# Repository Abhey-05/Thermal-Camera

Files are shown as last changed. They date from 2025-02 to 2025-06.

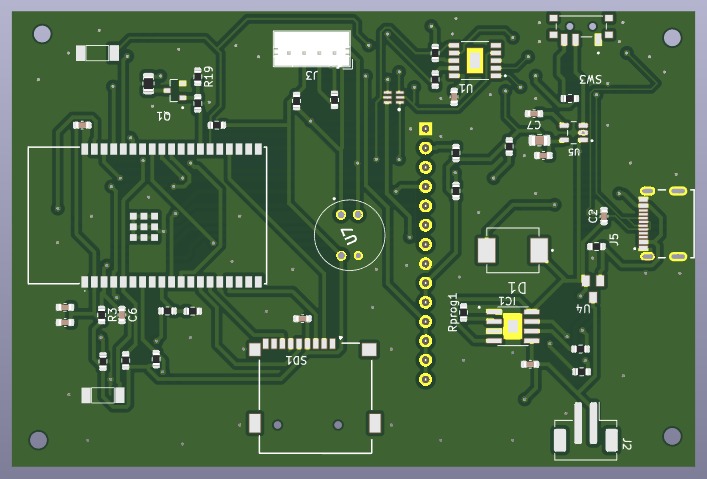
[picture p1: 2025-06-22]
Images/pcb2.jpeg

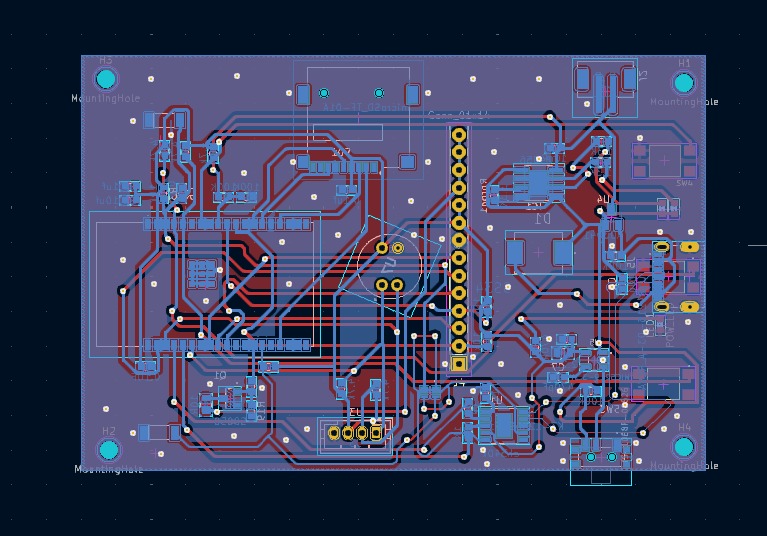
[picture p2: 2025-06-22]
Images/pcb3.jpeg

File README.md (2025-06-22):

<h1>
  Thermal Camera
</h1>
A compact, low-cost thermal imaging solution built for diagnostic, repair, and monitoring applications in electronics, industrial safety, and embedded systems. Unlike commercial thermal cameras that are often expensive, this DIY thermal imager is designed using readily available and affordable components, making it accessible for students, hobbyists, and engineers.

Thermal cameras play a critical role in detecting temperature anomalies, benchmarking heat performance, and assisting in electronic hardware debugging. Commonly used in defense, predictive maintenance, and the repair industry, thermal imaging enables faster and safer identification of faults such as short circuits or overheating components. Our project aims to replicate these capabilities at a fraction of the market cost.

<h2>Project Workflow </h2>

We began by understanding the working principles of thermal cameras and the core requirements of a low-cost system. The MLX90640 thermal sensor was selected for its high sensitivity and compact resolution, while the 2.4” TFT display offered a visually rich and user-friendly interface.

We wrote firmware from scratch to handle thermal data acquisition, color mapping, and display control using an ESP32 microcontroller. All SPI and I2C communication protocols were manually configured and tested for stability. We then implemented SD card image storage and added support for selectable color palettes and refresh rates.

The enclosure and power management were developed in parallel. A custom battery management system was integrated to allow portability, and the housing was designed to be compact yet thermally stable. The complete schematic and PCB were designed in KiCad.

<h2>
Features:
</h2>

- Image Sensor Resolution: 32×24 pixels
- Field of View (FoV): 55° × 35°
- Temperature Measurement Range: -40°C to 300°C
- Operating Temperature Range: -40°C to 85°C
- Adjustable Refresh Rate: 4 Hz to 32 Hz
- Color Palettes: 10 selectable thermal color schemes
- Display: 2.4" TFT screen with 320×240 resolution
- Storage: Supports saving thermal images to SD card
- Power: Built-in rechargeable battery with charging circuit

<h2>Schematic</h2>

WhatsApp Image 2025-06-22 at 16 25 18

<h2>PCB Layout </h2>

pcb1
pcb2
pcb3

<h2>Setup</h2>

WhatsApp Image 2025-06-22 at 16 26 38

<h2> Working Video </h2>

https://github.com/user-attachments/assets/c0b89b00-765c-46c9-96d5-a79226db0dfd

https://github.com/user-attachments/assets/fa7a4603-ffcd-4ff7-a3ee-2d5423cac2e8

<h2>Applications</h2>

- Electronics repair and thermal diagnostics
- Industrial safety monitoring
- DIY electronics and embedded systems projects
- Educational use for temperature visualization

<h2>Challenges Faced</h2>
 
- Occasional screen lag during rapid refresh.
- Difficulty in storing data reliably on the SD card due to SPI timing issues.
- Display showed only half-screen output initially, resolved through pin remapping and timing adjustments.

<h2>Team Members</h2>

- Abhey Garg (EE23BTECH11202)
- Chirag Garg (EE23BTECH11206)
- Prashant Maurya (EE23BTECH11218)
- Preetam (EE23BTECH11221)
- Sasa Mardi (EE23BTECH11222)

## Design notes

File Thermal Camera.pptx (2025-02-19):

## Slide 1

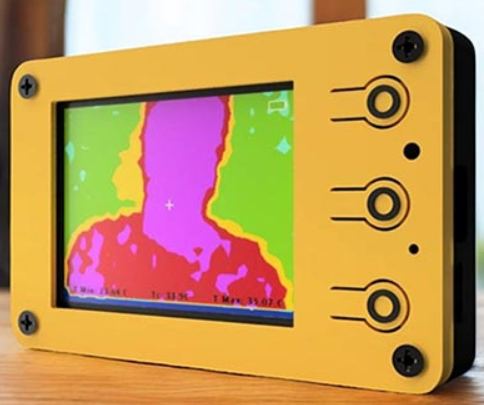
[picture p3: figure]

Thermal Sensing Camera

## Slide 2

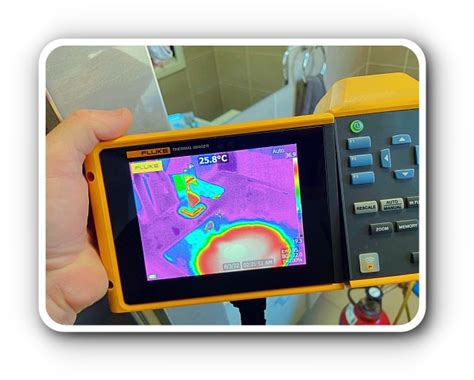
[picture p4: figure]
Thermal imaging | Water Leak Detection Pioneers

Project By:
Sasa Mardi ee23btech11222
Sai Preetam ee23btech11221
Abhey Garg ee23btech11202
Chirag Garg ee23btech11206
Prashant Maurya ee23btech11218

## Introduction

A DIY thermal camera using an ESP32 microcontroller and an MLX90640 thermal sensor offers an affordable and portable solution for thermal imaging. This project enables real-time heat detection by capturing infrared radiation and converting it into a visual temperature map displayed on an OLED or TFT screen. The ESP32 processes data from the MLX90640 sensor via the I2C protocol, rendering a thermal image that highlights temperature variations in the environment. Powered by a lithium-ion battery, this compact thermal camera is ideal for applications such as detecting heat loss in buildings, monitoring electronic components for overheating, and temperature screening.

## Major Components

1. IR SENSOR MLX90640 (32 x 24)
2. ESP32 Microcontroller
3. TFT Display(320 x 240)
4. Battery
5. SD Card

## Features

Sensor field of view (FoV): 55°x35°
Temperature measurement range: -40 to 300°C
-40 to 85°C operational temperature range
Adjustable refresh rate – 4Hz – 32Hz.10 different colour pallets
5 different interpolation modes.
Easy to use GUI.
2.4” TFT display with 320x240 resolution
Built-in battery and charging circuit.

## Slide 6

Power Input

3.3V Regulator

On/Off switch

Battery Charging

Display

LED Indicator

USB-UART/ Programming Circuit

ESP 32 SoC

Image Sensor

SD Card

## Work Flow

1. Data Acquisition: The MLX90640 sensor continuously reads the infrared radiation from its environment and transmits the data to the ESP32.
2. Data Processing: The ESP32 reads the data from the thermal sensor, processes the temperature information, and formats it into a readable thermal image.
3. Image Display: The processed data is sent to the display, where it is rendered as a color-coded thermal image. Different temperatures are represented by varying colors or shades.
4. Power Management: The battery supplies power to the ESP32 and the sensor, making it a portable system that can be used in a variety of environments.

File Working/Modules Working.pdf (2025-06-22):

# Thermal Camera System Design Overview

### USB Input and Power Path Control

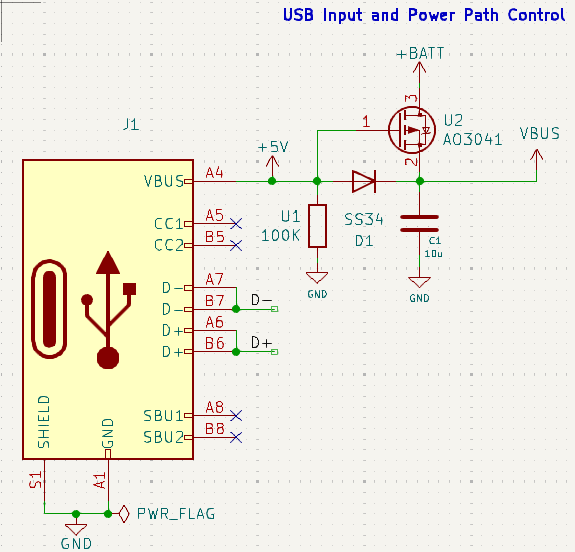
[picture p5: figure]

The USB input and power path control system is critical for managing the multiple power sources available to the thermal camera. It ensures the camera can operate seamlessly whether powered via USB or a battery.

A power multiplexer or ideal diode controller typically governs the transition, preventing back-powering and allowing simultaneous battery charging and device operation. The system must include overvoltage, overcurrent, and thermal protection mechanisms to ensure safety and reliability. Proper path control contributes to system robustness, ensuring no disruption when power sources are switched. This is essential for user convenience, especially in portable field use where the device may frequently switch between power modes.

### 3.3V Regulator

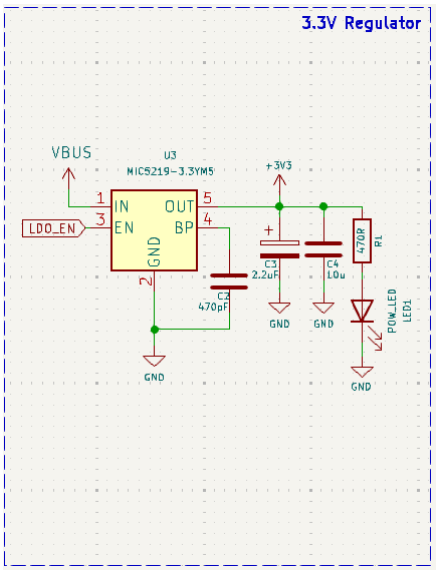
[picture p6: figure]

The 3.3V voltage regulator is tasked with converting a higher voltage (usually 5V from USB or battery boost converter) to a stable 3.3V rail. This is the operating voltage for key components like the ESP32 SoC, MLX90640 sensor, and display modules. Choosing between a linear regulator and a buck converter depends on system efficiency requirements. While linear regulators are simple, they waste excess voltage as heat.

Buck converters are more efficient, especially for battery applications, and reduce power loss. Clean 3.3V power is vital for stable wireless communication and accurate sensor data. Noise filtering and proper PCB layout techniques (e.g., decoupling capacitors) further enhance the stability of this power rail.

### Battery Charging Circuit

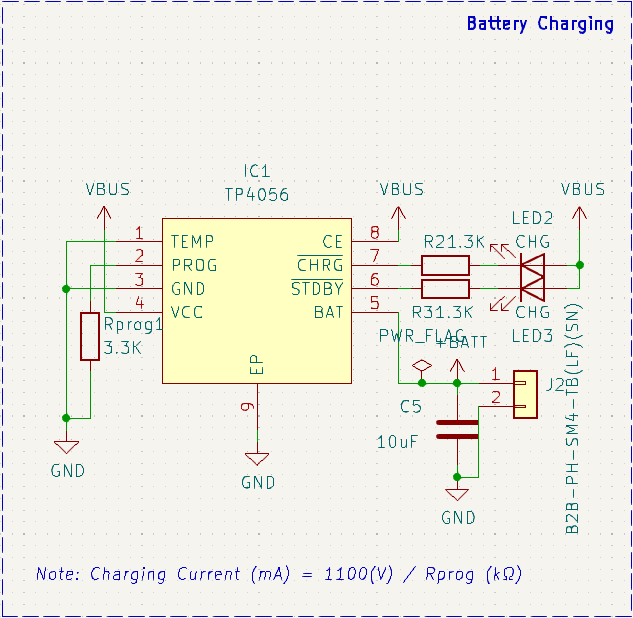
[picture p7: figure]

This module allows safe charging of a lithium-based battery pack from the USB input. It includes current regulation, voltage monitoring, and protection features such as thermal shutdown and trickle pre-charging for depleted cells.

A commonly used IC is the TP4056 or MCP73831. This circuit must be carefully designed to balance charge speed and battery lifespan.

It plays a crucial role in ensuring the thermal camera can be recharged quickly and safely while still operating. Additionally, some chargers support power path management, allowing the device to run off USB while the battery charges - an essential feature in mobile designs.

### TFT Display

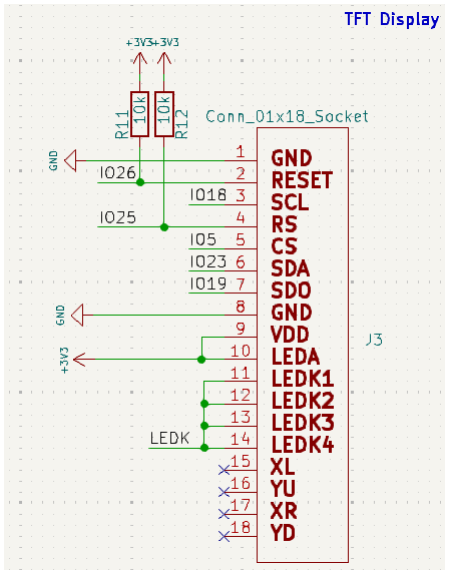
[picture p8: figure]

The TFT display acts as the primary output interface for the thermal camera, providing a graphical visualization of the thermal data. With resolutions like 240x320, it enables users to observe heat signatures and temperature gradients effectively.

It communicates with the ESP32 typically over SPI and requires careful initialization via display drivers. The display not only shows the thermal image but can also be used to display temperature values, color-coded heatmaps, or user menus.

Its size, resolution, and refresh rate significantly affect the user experience and system responsiveness. Good readability in various lighting conditions and low power consumption are key factors in selecting the right display.

### USB-UART Programming Circuit

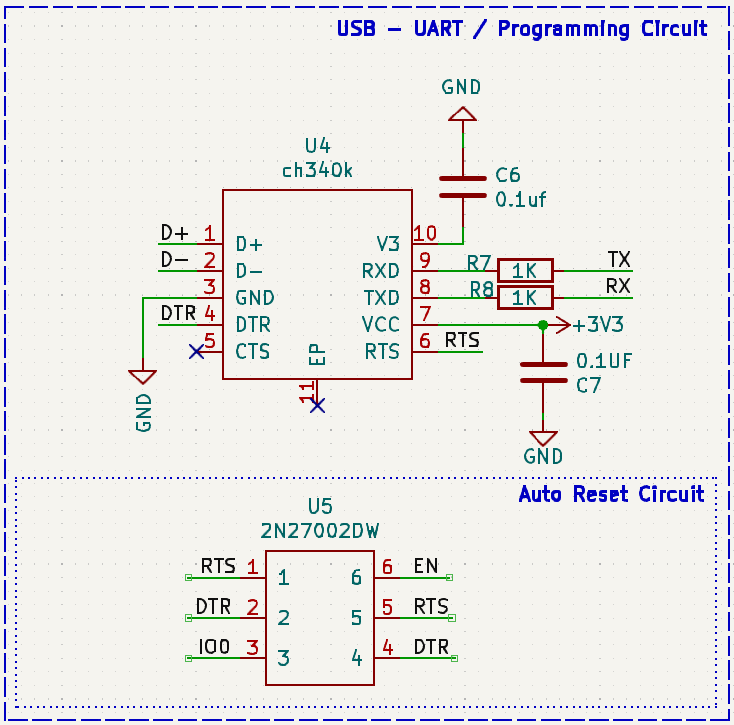
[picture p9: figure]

This circuit enables easy programming and debugging of the ESP32 via a USB connection. It includes a USB-to-serial converter chip such as CP2102, FTDI FT232, or CH340. This converter interfaces between the PC and the ESP32’s UART pins, allowing firmware uploads and serial communication.

It usually includes a DTR/RTS-driven auto-reset circuit for seamless programming from tools like the Arduino IDE or ESP-IDF. This circuit is vital during development and even useful in production for diagnostics. A reliable USB-UART bridge ensures consistent communication, enabling users to update firmware or log sensor data without opening the device.

### ESP32 SoC

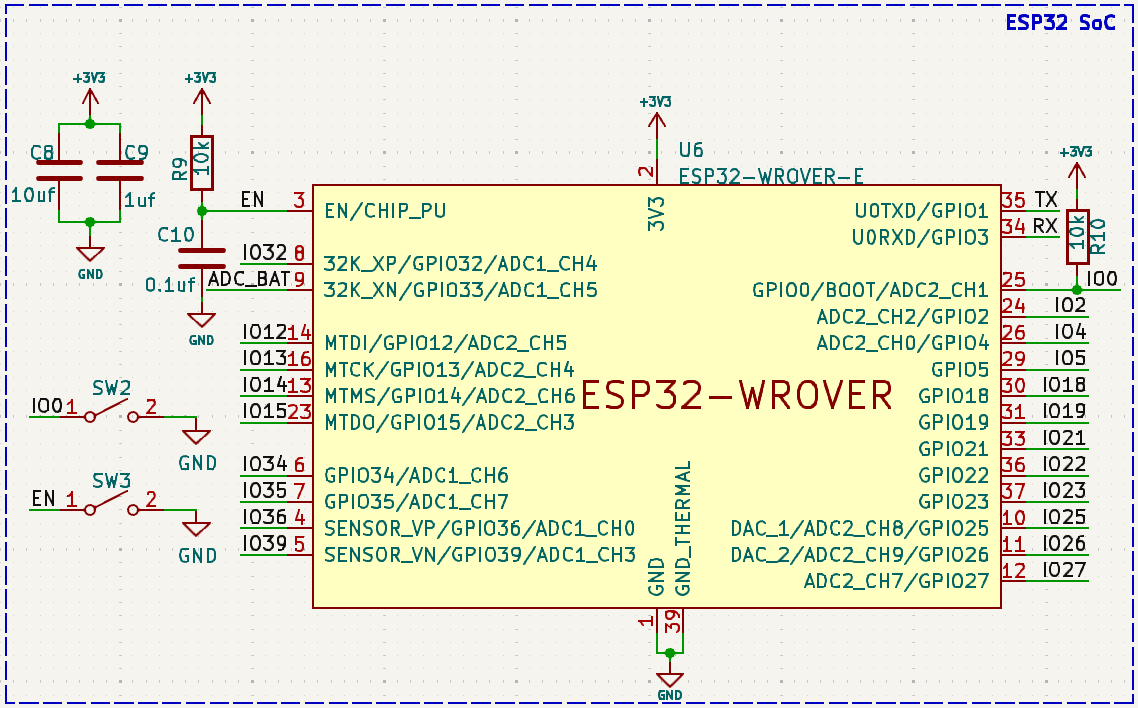
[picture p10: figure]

The ESP32 System-on-Chip (SoC) is the core of the thermal camera. It includes a dual-core processor, integrated Wi-Fi and Bluetooth, multiple GPIOs, ADCs, SPI/I2C/UART, and low-power modes. It interfaces with all peripherals, including the MLX90640 thermal sensor, the TFT display, and power management circuits. The ESP32 processes thermal data, applies temperature mapping algorithms, and renders visual outputs. Its wireless capabilities allow remote monitoring or control.

The ESP32’s programmability makes it ideal for embedded applications where performance, connectivity, and low power are needed. With adequate memory and speed, it handles image data and system control efficiently in real-time.

### MLX90640 Sensor

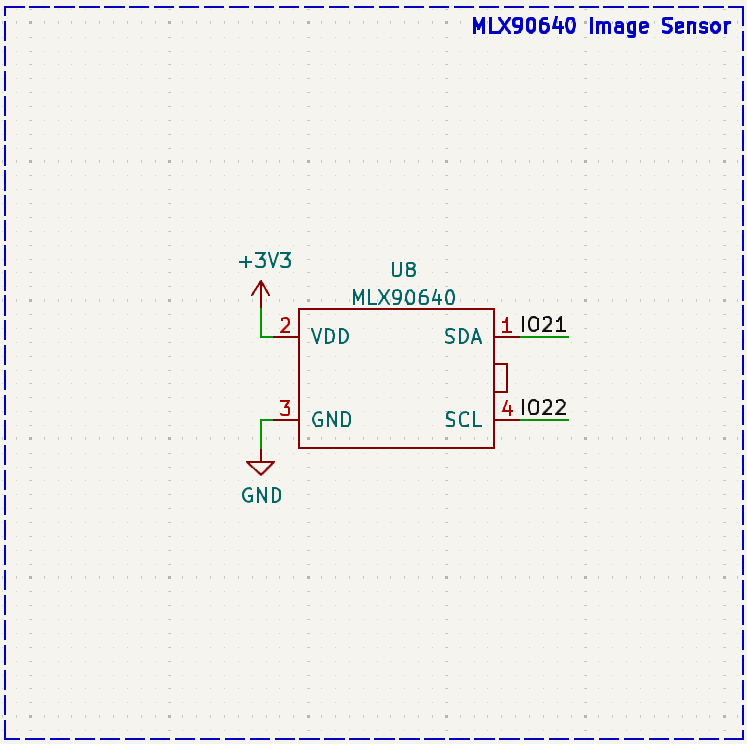
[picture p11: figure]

The MLX90640 is a 32x24 pixel thermal infrared sensor array that captures temperature data across its field of view. It senses infrared radiation to form a low-resolution thermal image and communicates with the ESP32 via I2C. Each pixel provides temperature readings that the ESP32 converts into a visual heat map. The sensor operates between -40°C to 300°C and is ideal for contactless temperature measurement. It includes onboard calibration and frame refresh control. Its compact size and low power consumption make it suitable for handheld thermal cameras.

Applications include human presence detection, energy audits, and heat leakage detection. It is the main imaging component of the thermal camera, delivering the raw thermal data essential for operation.

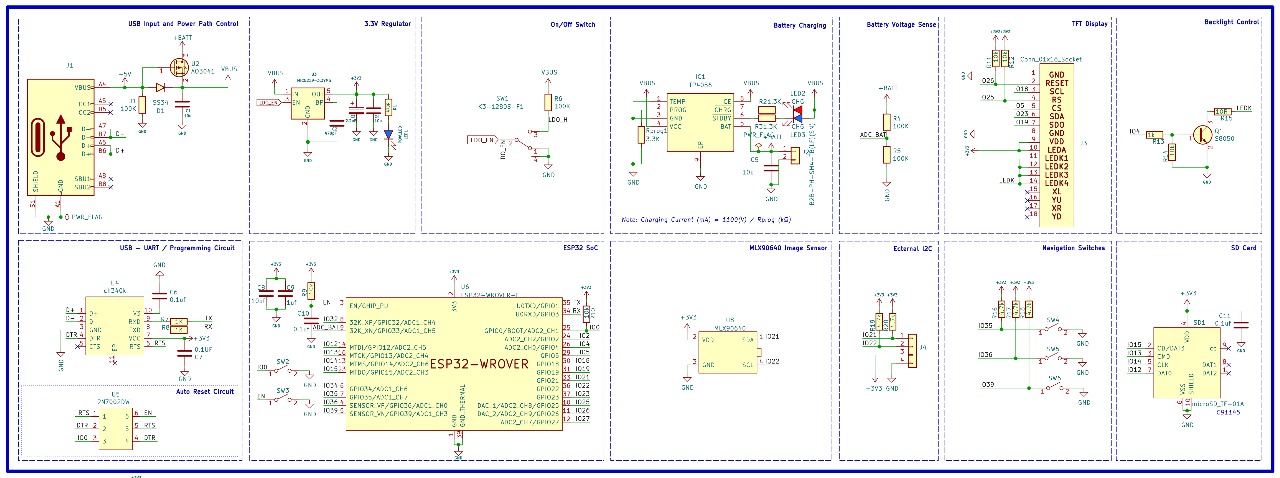
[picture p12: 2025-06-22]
Images/Schematic.jpeg

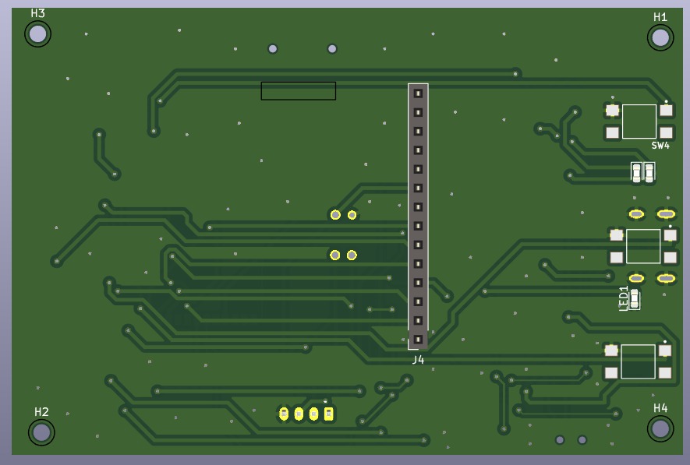
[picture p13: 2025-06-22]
Images/pcb1.jpeg

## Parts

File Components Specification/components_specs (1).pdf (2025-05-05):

# Component Specifications

# Contents

Component Specifications

## 0.1 ESP32-WROVER-E

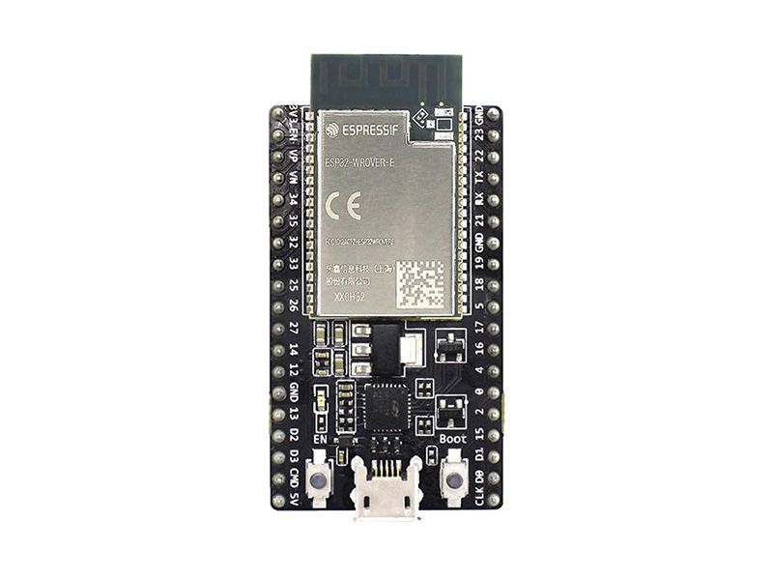
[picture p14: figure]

Figure 1: ESP32-WROVER-E Module

Specifications

- Chipset: ESP32-D0WD-V3 with dual-core Xtensa® 32-bit LX6 up to 240 MHz.
- Flash Memory: 4 MB external SPI flash.
- PSRAM: 8 MB SPI PSRAM.
- Wireless: Wi-Fi (802.11 b/g/n) + Bluetooth v4.2.
- Antenna: On-board or IPEX connector.
- Voltage: 3.0 V to 3.6 V (typical 3.3 V).
- Sleep Current: As low as 10 µA.
- GPIOs: 34.
- Interfaces: UART, SPI, I2C, etc.
- Peripherals: Hall sensor, temperature sensor, capacitive touch.
- Temperature: –40 °C to 85 °C.
- Dimensions: 18 × 31.4 × 3.3 mm.

## 0.2 MLX90640 Thermal Infrared Sensor

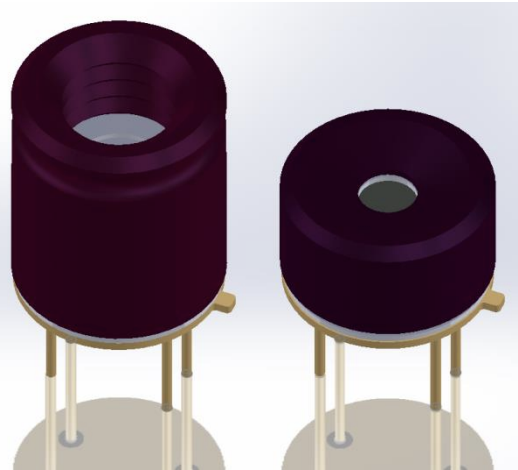
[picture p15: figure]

Figure 2: MLX90640 Thermal Sensor

Specifications

- Array: 32 × 24 pixels.
- Package: TO-39.
- Spectral Range: 7.5 – 13.5 µm.
- FOV: 55°×35°, 110°×75°, 40°×10°.
- Accuracy: ±1°C (0–50°C).
- Range: –40°C to +300°C.
- Sensitivity: 0.1 K.
- Voltage: 3.3V ±5%.
- Current: 23 mA.
- Interface: I²C.
- Frame Rate: 0.5 to 64 Hz.
- EEPROM: Internal.
- Pixel Pitch: 0.9 mm.
- Optical Axis: 6.52 mm from base.
- Size: 8.9 mm diameter × 10.9 mm height.
- Temp. Range: –40°C to +85°C (operating), –40°C to +125°C (storage).

## 0.3 LDO Voltage Regulator (XC6206P332MR)

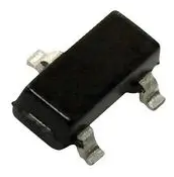
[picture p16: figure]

Figure 3: LDO Voltage Regulator

Specifications

- Model: XC6206P332MR
- Output Voltage: 3.3V
- Max Current: 250 mA
- Dropout: 250 mV @ 100 mA
- Input Range: 2.0V to 6.0V
- Accuracy: ±2%
- Quiescent Current: 8 µA
- Protection: Current limiter, thermal shutdown
- Package: SOT-23
- Applications: Battery systems, low-power microcontrollers

## 0.4 ILI9341 TFT Display

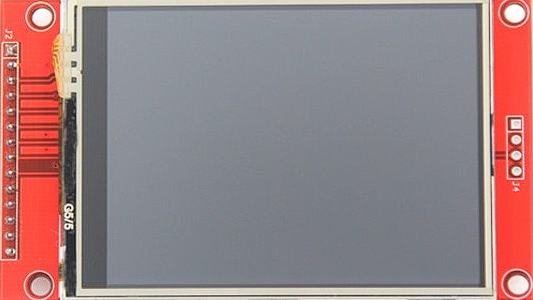
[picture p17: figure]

Figure 4: ILI9341 TFT Display

Specifications

- Type: TFT LCD
- Resolution: 240 × 320 pixels
- Size: 2.4” or 2.8”
- Colors: 262K
- Driver: ILI9341
- Interfaces: Parallel, SPI, RGB
- Voltages: 1.65V–3.3V (digital), 2.5V–3.3V (analog)
- Frame Memory: 172800 bytes
- Features: Power saving, display inversion, idle mode
- Touch: Not included
- Backlight: LED (external control)

## 0.5 CH340 USB to Serial Converter IC

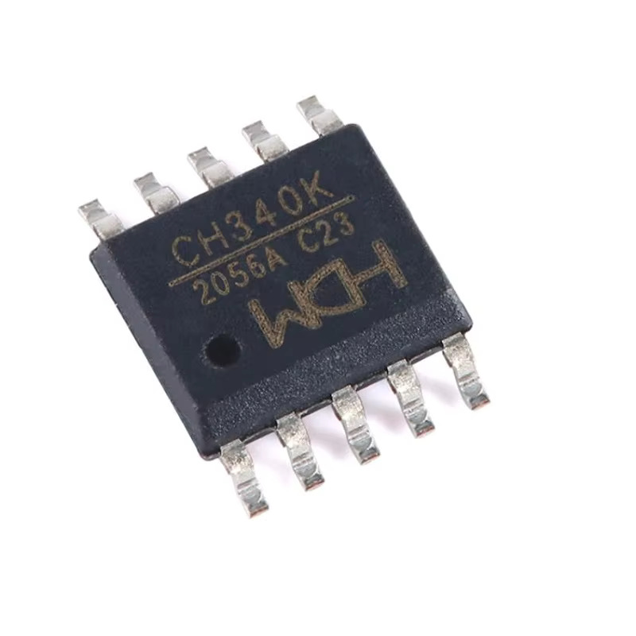
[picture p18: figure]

Figure 5: CH340 USB to Serial Converter IC

Specifications

- Type: USB to UART bridge
- USB: 1.1, 2.0, 3.0 compatible
- Voltage: 5V (CH340G), supports 3.3V logic
- Baud Rate: 50 bps to 2 Mbps
- Package: SOP-16
- Oscillator: 12 MHz crystal required
- Drivers: Needed on Windows
- Interfaces: TXD, RXD, RTS, CTS, etc.
- Flow Control: Hardware software supported
- Applications: USB-to-serial, embedded systems

## 0.6 TP4056 Li-Ion Battery Charging IC

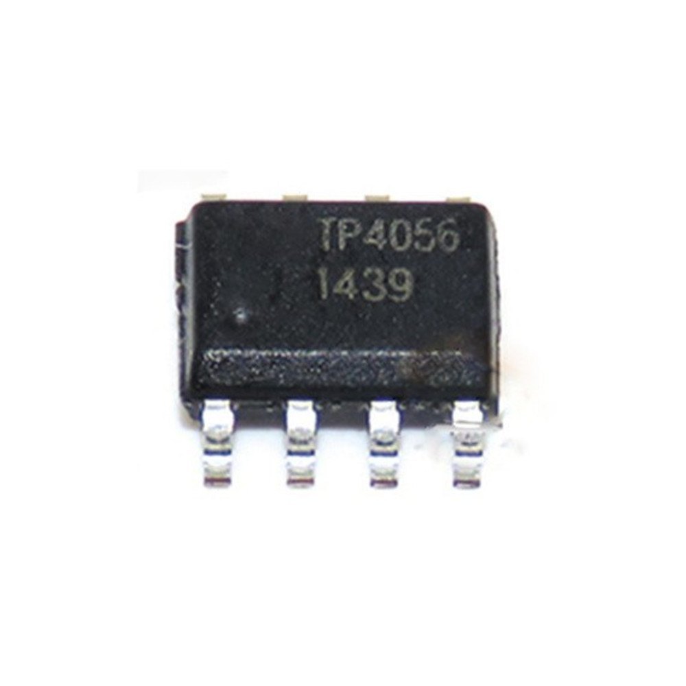
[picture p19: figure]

Figure 6: TP4056 Charging IC

Specifications

- Type: Linear Li-Ion Charger
- Charge Voltage: 4.2V
- Charge Current: Up to 1000 mA
- Package: ESOP-8
- Input Voltage: 4.0V to 8.0V
- Indication: STAT pin (active low)
- Trickle Threshold: 2.9V
- Accuracy: ±1.5%
- Standby Current: 100 µA
- Protections: Thermal, battery temp, recharge
- Applications: Power banks, portable devices

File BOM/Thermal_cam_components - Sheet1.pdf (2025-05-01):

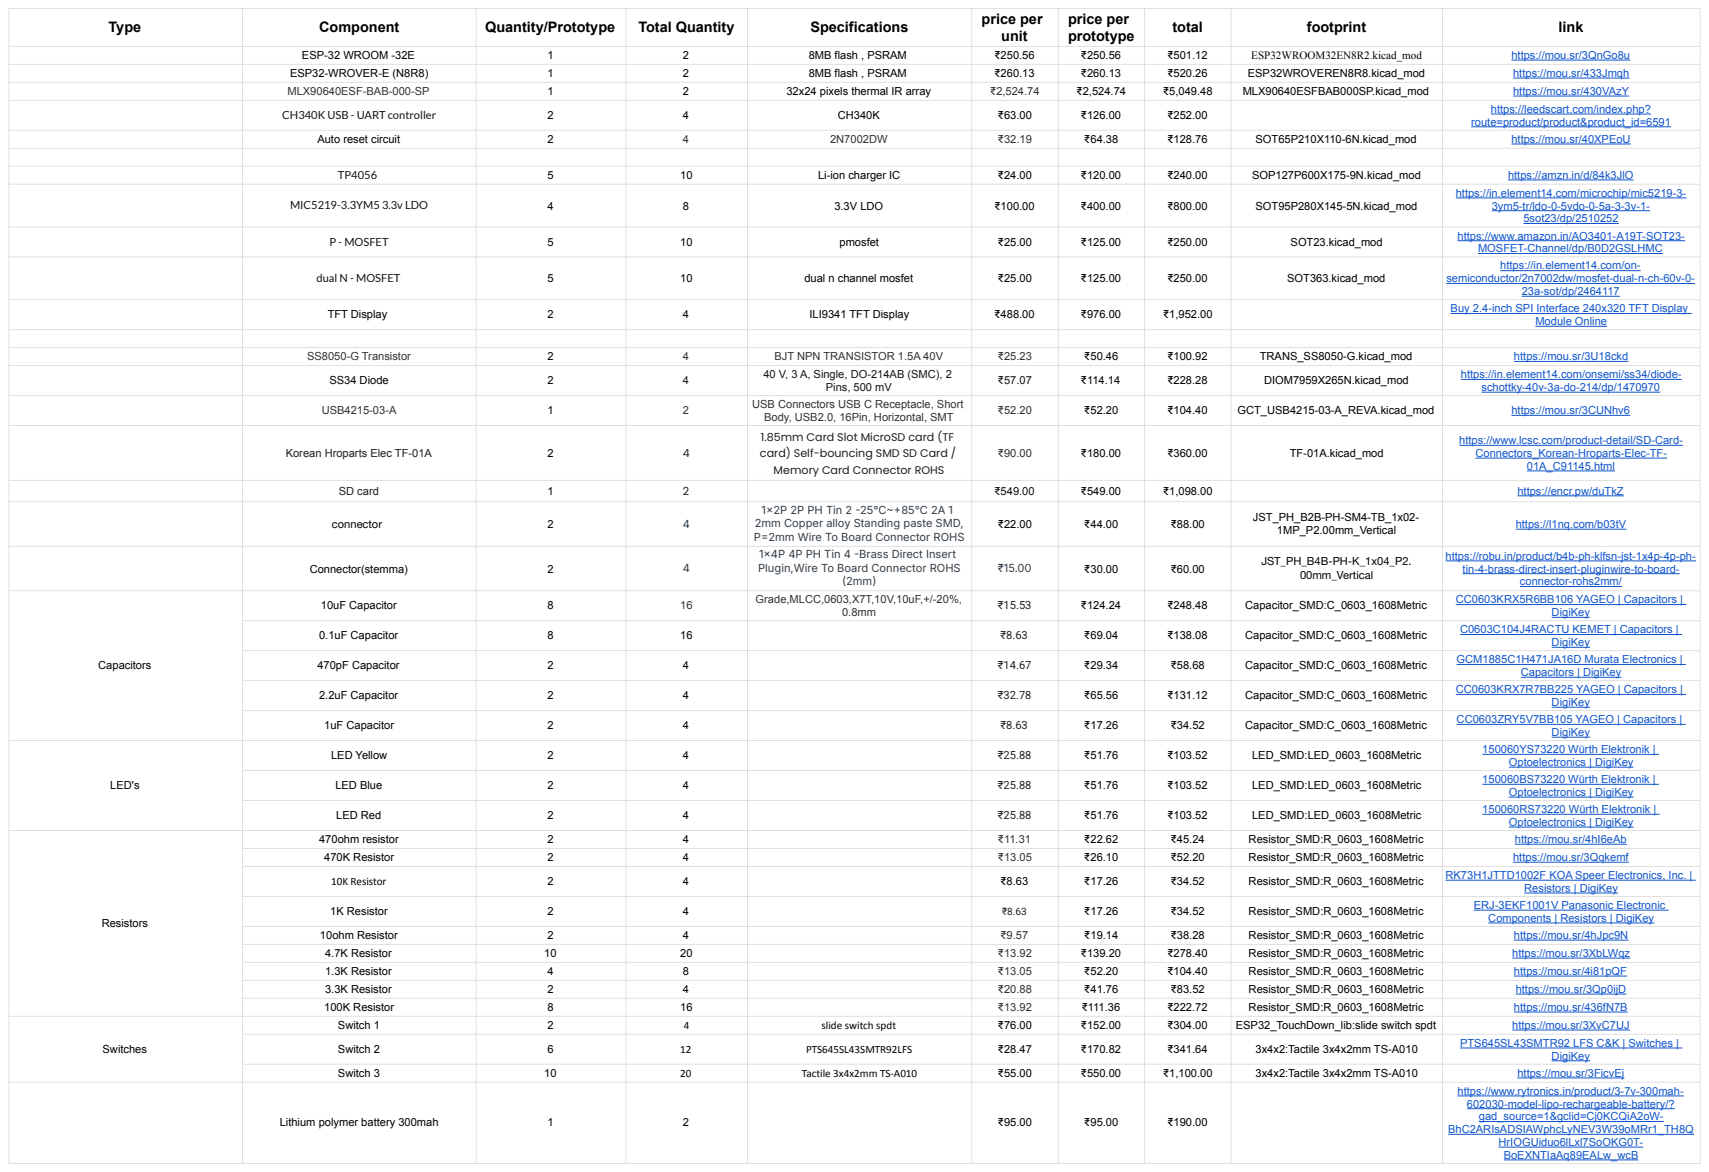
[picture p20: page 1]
Type; Component; Quantity/Prototype; Total Quantity; Specifications; price per unit; price per; prototype; total; footprint; link; ESP-32 WROOM -32E; 8MB flash , PSRAM; ESP32WROOM32EN8R2.kicad_mod; https://mou.sr/3QnGo8u; ESP32-WROVER-E (N8R8); ESP32WROVEREN8R8.kicad_mod; https://mou.sr/433Jmqh MLX90640ESF-BAB-000-SP; 32x24 pixels thermal IR array; MLX90640ESFBAB000SP.kicad_mod; https://mou.sr/430VAzY; Li-ion charger IC; SOP127P600X175-9N.kicad_mod; https://amzn.in/d/84k3JlO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

CH340K USB - UART controller | 2 4 CH340K ₹63.00 ₹126.00 ₹252.00 https://leedscart.com/index.php?route=product/product&product_id=6591 (https://www.lcsc.com/product-detail/USB-Converters_WCH-Jiangsu-Qin-Heng-CH340K_C968586.html)

Auto reset circuit 2 | 4 2N7002DW ₹32.19 | ₹64.38 ₹128.76 SOT65P210X110-6N.kicad_mod https://mou.sr/40XPEoU

https://in.element14.com/microchip/mic5219-3- 3ym5-tr/ldo-0-5vdo-0-5a-3-3v-1- 5sot23/dp/2510252

semiconductor/2n7002dw/mosfet-dual-n-ch-60v-0- (https://in.element14.com/on-semiconductor/2n7002dw/mosfet-dual-n-ch-60v-0-23a-sot/dp/2464117) 23a-sot/dp/2464117

https://in.element14.com/on-

SS8050-G Transistor 2 SS34 Diode 2 USB4215-03-A 1 | 4 BJT NPN TRANSISTOR 1.5A 40V ₹25.23 40 V, 3 A, Single, DO-214AB (SMC), 2 Pins, 500 mV ₹57.07 4 2 USB Connectors USB C Receptacle, Short Body, USB2.0, 16Pin, Horizontal, SMT ₹52.20 | ₹50.46 ₹100.92 TRANS_SS8050-G.kicad_mod https://mou.sr/3U18ckd ₹114.14 ₹228.28 DIOM7959X265N.kicad_mod https://in.element14.com/onsemi/ss34/diode-schottky-40v-3a-do-214/dp/1470970 (https://in.element14.com/onsemi/ss34/diode-schottky-40v-3a-do-214/dp/1470970) ₹52.20 ₹104.40 GCT_USB4215-03-A_REVA.kicad_mod https://mou.sr/3CUNhv6

Korean Hroparts Elec TF-01A SD card | 2 1 | 1.85mm Card Slot MicroSD card (TF 4 card) Self-bouncing SMD SD Card / ₹90.00 Memory Card Connector ROHS 2 ₹549.00 | https://www.lcsc.com/product-detail/SD-Card- Connectors_Korean-Hroparts-Elec-TF- 01A_C91145.html ₹180.00 ₹360.00 TF-01A.kicad_mod ₹549.00 ₹1,098.00 https://encr.pw/duTkZ

12P 2P PH Tin 2 25℃85℃ 2A 1 2mm Copper alloy Standing paste SMD, P2mm Wire To Board Connector ROHS 14P 4P PH Tin 4 Brass Direct Insert Plugin,Wire To Board Connector ROHS 2mm | ₹22.00 ₹44.00 ₹88.00 JST_PH_B2B-PH-SM4-TB_1x02- 1MP_P2.00mm_Vertical https://l1nq.com/b03tV

₹15.00 | https://robu.in/product/b4b-ph-klfsn-jst-1x4p-4p-ph-₹30.00 ₹60.00 JST_PH_B4B-PH-K_1x04_P2. 00mm_Vertical

tin-4-brass-direct-insert-pluginwire-to-board-

https://www.rytronics.in/product/3-7v-300mah- 602030-model-lipo-rechargeable-battery/?

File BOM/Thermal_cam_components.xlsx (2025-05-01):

Type | Component | Quantity/Prototype | Total Quantity | Specifications | price per unit | price per prototype | total | footprint | link
 | ESP-32 WROOM -32E | 1 | 2 | 8MB flash , PSRAM | ₹250.56 | ₹250.56 | ₹501.12 | ESP32WROOM32EN8R2.kicad_mod | https://mou.sr/3QnGo8u
 | ESP32-WROVER-E (N8R8) | 1 | 2 | 8MB flash , PSRAM | ₹260.13 | ₹260.13 | ₹520.26 | ESP32WROVEREN8R8.kicad_mod | https://mou.sr/433Jmqh
 | MLX90640ESF-BAB-000-SP | 1 | 2 | 32x24 pixels thermal IR array | ₹2524.74 | ₹2524.74 | ₹5049.48 | MLX90640ESFBAB000SP.kicad_mod | https://mou.sr/430VAzY
 | CH340K USB - UART controller | 2 | 4 | CH340K | ₹63.00 | ₹126.00 | ₹252.00 |  | https://leedscart.com/index.php?route=product/product&product_id=6591 (https://www.lcsc.com/product-detail/USB-Converters_WCH-Jiangsu-Qin-Heng-CH340K_C968586.html)
 | Auto reset circuit | 2 | 4 | 2N7002DW | ₹32.19 | ₹64.38 | ₹128.76 | SOT65P210X110-6N.kicad_mod | https://mou.sr/40XPEoU
 | TP4056 | 5 | 10 | Li-ion charger IC | ₹24.00 | ₹120.00 | ₹240.00 | SOP127P600X175-9N.kicad_mod | https://amzn.in/d/84k3JlO
 | MIC5219-3.3YM5 3.3v LDO | 4 | 8 | 3.3V LDO | ₹100.00 | ₹400.00 | ₹800.00 | SOT95P280X145-5N.kicad_mod | https://in.element14.com/microchip/mic5219-3-3ym5-tr/ldo-0-5vdo-0-5a-3-3v-1-5sot23/dp/2510252
 | P - MOSFET | 5 | 10 | pmosfet | ₹25.00 | ₹125.00 | ₹250.00 | SOT23.kicad_mod | https://www.amazon.in/AO3401-A19T-SOT23-MOSFET-Channel/dp/B0D2GSLHMC
 | dual N - MOSFET | 5 | 10 | dual n channel mosfet | ₹25.00 | ₹125.00 | ₹250.00 | SOT363.kicad_mod | https://in.element14.com/on-semiconductor/2n7002dw/mosfet-dual-n-ch-60v-0-23a-sot/dp/2464117
 | TFT Display | 2 | 4 | ILI9341 TFT Display | ₹488.00 | ₹976.00 | ₹1952.00 |  | Buy 2.4-inch SPI Interface 240x320 TFT Display Module Online (https://robu.in/product/2-4-inch-spi-interface-240x320-touch-screen-tft-display-module/)
 | SS8050-G Transistor | 2 | 4 | BJT NPN TRANSISTOR 1.5A 40V | ₹25.23 | ₹50.46 | ₹100.92 | TRANS_SS8050-G.kicad_mod | https://mou.sr/3U18ckd
 | SS34 Diode | 2 | 4 | 40 V, 3 A, Single, DO-214AB (SMC), 2 Pins, 500 mV | ₹57.07 | ₹114.14 | ₹228.28 | DIOM7959X265N.kicad_mod | https://in.element14.com/onsemi/ss34/diode-schottky-40v-3a-do-214/dp/1470970
 | USB4215-03-A | 1 | 2 | USB Connectors USB C Receptacle, Short Body, USB2.0, 16Pin, Horizontal, SMT | ₹52.20 | ₹52.20 | ₹104.40 | GCT_USB4215-03-A_REVA.kicad_mod | https://mou.sr/3CUNhv6
 | Korean Hroparts Elec TF-01A | 2 | 4 | 1.85mm Card Slot MicroSD card (TF card) Self-bouncing SMD SD Card / Memory Card Connector ROHS | ₹90.00 | ₹180.00 | ₹360.00 | TF-01A.kicad_mod | https://www.lcsc.com/product-detail/SD-Card-Connectors_Korean-Hroparts-Elec-TF-01A_C91145.html
 | SD card | 1 | 2 |  | ₹549.00 | ₹549.00 | ₹1098.00 |  | https://encr.pw/duTkZ
 | connector | 2 | 4 | 1x2P 2P PH Tin 2 -25℃~+85℃ 2A 1 2mm Copper alloy Standing paste SMD,P=2mm Wire To Board Connector ROHS | ₹22.00 | ₹44.00 | ₹88.00 | JST_PH_B2B-PH-SM4-TB_1x02-1MP_P2.00mm_Vertical | https://l1nq.com/b03tV
 | Connector(stemma) | 2 | 4 | 1x4P 4P PH Tin 4 -Brass Direct Insert Plugin,Wire To Board Connector ROHS(2mm) | ₹15.00 | ₹30.00 | ₹60.00 | JST_PH_B4B-PH-K_1x04_P2.00mm_Vertical | https://robu.in/product/b4b-ph-klfsn-jst-1x4p-4p-ph-tin-4-brass-direct-insert-pluginwire-to-board-connector-rohs2mm/
Capacitors | 10uF Capacitor | 8 | 16 | Grade,MLCC,0603,X7T,10V,10uF,+/-20%,0.8mm | ₹15.53 | ₹124.24 | ₹248.48 | Capacitor_SMD:C_0603_1608Metric | CC0603KRX5R6BB106 YAGEO | Capacitors | DigiKey (https://www.digikey.in/en/products/detail/yageo/CC0603KRX5R6BB106/5195191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)
 | 0.1uF Capacitor | 8 | 16 |  | ₹8.63 | ₹69.04 | ₹138.08 | Capacitor_SMD:C_0603_1608Metric | C0603C104J4RACTU KEMET | Capacitors | DigiKey (https://www.digikey.in/en/products/detail/kemet/C0603C104J4RACTU/411096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)
 | 470pF Capacitor | 2 | 4 |  | ₹14.67 | ₹29.34 | ₹58.68 | Capacitor_SMD:C_0603_1608Metric | GCM1885C1H471JA16D Murata Electronics | Capacitors | DigiKey (https://www.digikey.in/en/products/detail/murata-electronics/GCM1885C1H471JA16D/1765213)
 | 2.2uF Capacitor | 2 | 4 |  | ₹32.78 | ₹65.56 | ₹131.12 | Capacitor_SMD:C_0603_1608Metric | CC0603KRX7R7BB225 YAGEO | Capacitors | DigiKey (https://www.digikey.in/en/products/detail/yageo/CC0603KRX7R7BB225/7164374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)
 | 1uF Capacitor | 2 | 4 |  | ₹8.63 | ₹17.26 | ₹34.52 | Capacitor_SMD:C_0603_1608Metric | CC0603ZRY5V7BB105 YAGEO | Capacitors | DigiKey (https://www.digikey.in/en/products/detail/yageo/CC0603ZRY5V7BB105/2103110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)
LED's | LED Yellow | 2 | 4 |  | ₹25.88 | ₹51.76 | ₹103.52 | LED_SMD:LED_0603_1608Metric | 150060YS73220 Würth Elektronik | Optoelectronics | DigiKey (https://www.digikey.in/en/products/detail/w%C3%BCrth-elektronik/150060YS73220/8557163)
 | LED Blue | 2 | 4 |  | ₹25.88 | ₹51.76 | ₹103.52 | LED_SMD:LED_0603_1608Metric | 150060BS73220 Würth Elektronik | Optoelectronics | DigiKey (https://www.digikey.in/en/products/detail/w%C3%BCrth-elektronik/150060BS73220/8557159)
 | LED Red | 2 | 4 |  | ₹25.88 | ₹51.76 | ₹103.52 | LED_SMD:LED_0603_1608Metric | 150060RS73220 Würth Elektronik | Optoelectronics | DigiKey (https://www.digikey.in/en/products/detail/w%C3%BCrth-elektronik/150060RS73220/8557161)
Resistors | 470ohm resistor | 2 | 4 |  | ₹11.31 | ₹22.62 | ₹45.24 | Resistor_SMD:R_0603_1608Metric | https://mou.sr/4hI6eAb
 | 470K Resistor | 2 | 4 |  | ₹13.05 | ₹26.10 | ₹52.20 | Resistor_SMD:R_0603_1608Metric | https://mou.sr/3Qqkemf
 | 10K Resistor | 2 | 4 |  | ₹8.63 | ₹17.26 | ₹34.52 | Resistor_SMD:R_0603_1608Metric | RK73H1JTTD1002F KOA Speer Electronics, Inc. | Resistors | DigiKey (https://www.digikey.in/en/products/detail/koa-speer-electronics-inc/RK73H1JTTD1002F/9844954)
 | 1K Resistor | 2 | 4 |  | ₹8.63 | ₹17.26 | ₹34.52 | Resistor_SMD:R_0603_1608Metric | ERJ-3EKF1001V Panasonic Electronic Components | Resistors | DigiKey (https://www.digikey.in/en/products/detail/panasonic-electronic-components/ERJ-3EKF1001V/196032)
 | 10ohm Resistor | 2 | 4 |  | ₹9.57 | ₹19.14 | ₹38.28 | Resistor_SMD:R_0603_1608Metric | https://mou.sr/4hJpc9N
 | 4.7K Resistor | 10 | 20 |  | ₹13.92 | ₹139.20 | ₹278.40 | Resistor_SMD:R_0603_1608Metric | https://mou.sr/3XbLWqz
 | 1.3K Resistor | 4 | 8 |  | ₹13.05 | ₹52.20 | ₹104.40 | Resistor_SMD:R_0603_1608Metric | https://mou.sr/4i81pQF
 | 3.3K Resistor | 2 | 4 |  | ₹20.88 | ₹41.76 | ₹83.52 | Resistor_SMD:R_0603_1608Metric | https://mou.sr/3Qp0ijD
 | 100K Resistor | 8 | 16 |  | ₹13.92 | ₹111.36 | ₹222.72 | Resistor_SMD:R_0603_1608Metric | https://mou.sr/436fN7B
Switches | Switch 1 | 2 | 4 | slide switch spdt | ₹76.00 | ₹152.00 | ₹304.00 | ESP32_TouchDown_lib:slide switch spdt | https://mou.sr/3XvC7UJ
 | Switch 2 | 6 | 12 | PTS645SL43SMTR92LFS | ₹28.47 | ₹170.82 | ₹341.64 | 3x4x2:Tactile 3x4x2mm TS-A010 | PTS645SL43SMTR92 LFS C&K | Switches | DigiKey (https://www.digikey.in/en/products/detail/c-k/PTS645SL43SMTR92-LFS/3861373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)
 | Switch 3 | 10 | 20 | Tactile 3x4x2mm TS-A010 | ₹55.00 | ₹550.00 | ₹1100.00 | 3x4x2:Tactile 3x4x2mm TS-A010 | https://mou.sr/3FicvEj
 | Lithium polymer battery 300mah | 1 | 2 |  | ₹95.00 | ₹95.00 | ₹190.00 |  | https://www.rytronics.in/product/3-7v-300mah-602030-model-lipo-rechargeable-battery/?gad_source=1

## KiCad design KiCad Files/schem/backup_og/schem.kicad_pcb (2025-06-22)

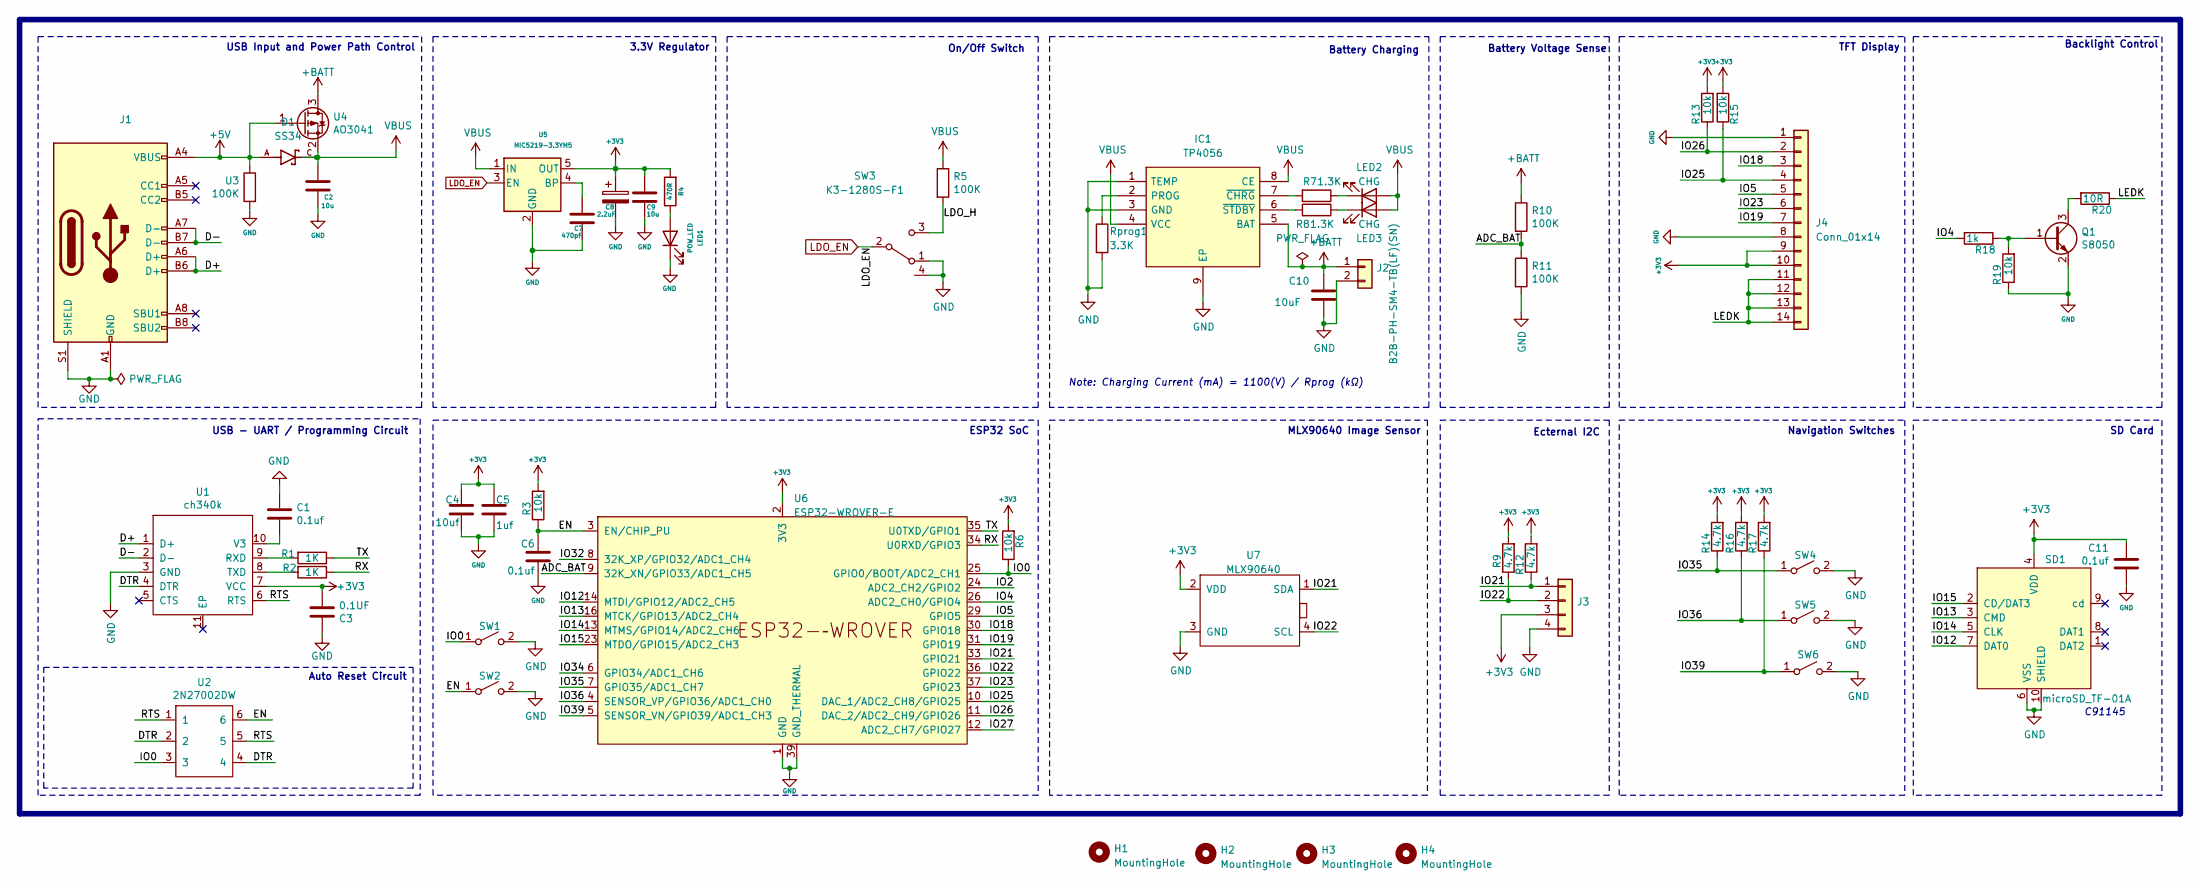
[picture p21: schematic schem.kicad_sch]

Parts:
C1, C6, C11: 0.1uf; C_0603_1608Metric
C2, C9: 10u; C_0603_1608Metric
C3: 0.1UF; C_0603_1608Metric
C4: 10uf; C_0603_1608Metric
C5: 1uf; C_0603_1608Metric
C7: 470pF; C_0603_1608Metric
C8: 2.2uF; C_0805_2012Metric
C10: 10uF; C_0603_1608Metric
D1: SS34; SS34_DIODE_NEW; PARTREV 31 Aug 2016
H1, H2, H3, H4: MountingHole; MountingHole_2.2mm_M2_ISO7380_Pad
IC1: TP4056; TP4056_SOP127P600X175-9N_TC; Manufacturer_Part_Number TP4056-42-ESOP8
J1: USB_C_Receptacle_USB2.0; USB_C_Receptacle_HRO_TYPE-C-31-M-12
J2: B2B-PH-SM4-TB(LF)(SN); JST_PH_B2B-PH-SM4-TB_1x02-1MP_P2.00mm_Vertical
J3: Stemma; JST_PH_B4B-PH-K_1x04_P2.00mm_Vertical
J4: Conn_01x14; PinSocket_1x14_P2.54mm_Vertical
LED1: POW_LED; LED_0603_1608Metric
LED2, LED3: CHG; LED_0603_1608Metric
Q1: S8050; TRANS_SS8050-G_TC
R1, R2: 1K; R_0603_1608Metric
R3, R6, R13, R15, R19: 10k; R_0603_1608Metric
R4: 470R; R_0603_1608Metric
R5, R10, R11: 100K; R_0603_1608Metric
R7, R8: 1.3K; R_0603_1608Metric
R9, R12, R14, R16, R17: 4.7k; R_0603_1608Metric
R18: 1k; R_0603_1608Metric
R20: 10R; R_0805_2012Metric
Rprog1: 3.3K; R_0603_1608Metric
SD1: microSD_TF-01A; sdcard_reader_TC
SW1, SW2: TS-1088R-02526; 2_TACTILE
SW3: K3-1280S-F1; slide_switch_TC
SW4, SW5, SW6: TS-1088R-02526; 4_TERMINAL_SWITCH_TC
U1: ch340k; ch340k_TC
U2: 2N27002DW; 2N7002DW_SOT363_TC
U3: 100K; R_0603_1608Metric
U4: AO3041; AO3401_SOT23_TC
U5: MIC5219-3.3YM5; MIC5219_SOT95P280X145-5N_TC
U6: ESP32-WROVER-E; ESP32WROVEREN8R8_TC
U7: MLX90640; MLX90640_ESFBAB000SP_TC

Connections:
+3V3: C3.2, C4.1, C5.1, C8.1, C9.1, C11.1, J3.3, J4.9, J4.10, R3.2, R4.2, R6.2, R9.2, R12.2, R13.2, R14.2, R15.2, R16.2, R17.2, SD1.4 (VDD), U1.7 (VCC), U5.5 (OUT), U6.2 (3V3), U7.2 (VDD)
+5V: D1.A, J1.A4 (VBUS), J1.A9 (VBUS), J1.B4 (VBUS), J1.B9 (VBUS), U3.1, U4.1 (G)
+BATT: C10.1, IC1.5 (BAT), J2.1, R10.1, U4.3 (D)
/ADC_BAT: R10.2, R11.1, U6.9 (32K_XN/GPIO33/ADC1_CH5)
/D+: J1.A6 (D+), J1.B6 (D+), U1.1 (D+)
/D-: J1.A7 (D-), J1.B7 (D-), U1.2 (D-)
/DTR: U1.4 (DTR), U2.2, U2.4
/EN: C6.1, R3.1, SW2.1 (A), U2.6, U6.3 (EN/CHIP_PU)
/IO0: R6.1, SW1.1 (A), U2.3, U6.25 (GPIO0/BOOT/ADC2_CH1)
/IO2: U6.24 (ADC2_CH2/GPIO2)
/IO4: R18.2, U6.26 (ADC2_CH0/GPIO4)
/IO5: J4.5, U6.29 (GPIO5)
/IO12: SD1.7 (DAT0), U6.14 (MTDI/GPIO12/ADC2_CH5)
/IO13: SD1.3 (CMD), U6.16 (MTCK/GPIO13/ADC2_CH4)
/IO14: SD1.5 (CLK), U6.13 (MTMS/GPIO14/ADC2_CH6)
/IO15: SD1.2 (CD/DAT3), U6.23 (MTDO/GPIO15/ADC2_CH3)
/IO18: J4.3, U6.30 (GPIO18)
/IO19: J4.7, U6.31 (GPIO19)
/IO21: J3.1, R12.1, U6.33 (GPIO21), U7.1 (SDA)
/IO22: J3.2, R9.1, U6.36 (GPIO22), U7.4 (SCL)
/IO23: J4.6, U6.37 (GPIO23)
/IO25: J4.4, R15.1, U6.10 (DAC_1/ADC2_CH8/GPIO25)
/IO26: J4.2, R13.1, U6.11 (DAC_2/ADC2_CH9/GPIO26)
/IO27: U6.12 (ADC2_CH7/GPIO27)
/IO32: U6.8 (32K_XP/GPIO32/ADC1_CH4)
/IO34: U6.6 (GPIO34/ADC1_CH6)
/IO35: R14.1, SW4.1 (A), U6.7 (GPIO35/ADC1_CH7)
/IO36: R16.1, SW5.1 (A), U6.4 (SENSOR_VP/GPIO36/ADC1_CH0)
/IO39: R17.1, SW6.1 (A), U6.5 (SENSOR_VN/GPIO39/ADC1_CH3)
/LDO_H: R5.2, SW3.3 (C)
/LEDK: J4.11, J4.12, J4.13, J4.14, R20.1
/RTS: U1.6 (RTS), U2.1, U2.5
/RX: R2.1, U6.34 (U0RXD/GPIO3)
/TX: R1.1, U6.35 (U0TXD/GPIO1)
GND: C1.1, C2.2, C3.1, C4.2, C5.2, C6.2, C7.2, C8.2, C9.2, C10.2, C11.2, IC1.1 (TEMP), IC1.3 (GND), IC1.9 (EP), J1.A1 (GND), J1.A12 (GND), J1.B1 (GND), J1.B12 (GND), J1.S1 (SHIELD), J2.2, J3.4, J4.1, J4.8, LED1.1 (K), Q1.2 (B), R11.2, R19.1, Rprog1.2, SD1.6 (VSS), SD1.10 (SHIELD), SW1.2 (B), SW2.2 (B), SW3.1 (A), SW3.4, SW4.2 (B), SW5.2 (B), SW6.2 (B), U1.3 (GND), U3.2, U5.2 (GND), U6.1 (GND), U6.15 (GND), U6.38 (GND), U6.39 (GND_THERMAL), U7.3 (GND)
LDO_EN: SW3.2 (B), U5.3 (EN)
unnamed: IC1.2 (PROG), Rprog1.1
unnamed: IC1.7 (~CHRG), R7.2
unnamed: IC1.6 (~STDBY), R8.2
unnamed: LED1.2 (A), R4.1
unnamed: LED2.1 (K), R7.1
unnamed: LED3.1 (K), R8.1
unnamed: Q1.3 (C), R20.2
unnamed: Q1.1 (E), R18.1, R19.2
unnamed: R1.2, U1.9 (RXD)
unnamed: R2.2, U1.8 (TXD)
unnamed: C1.2, U1.10 (V3)
unnamed: C7.1, U5.4 (BP)
VBUS: C2.1, D1.C, IC1.4 (VCC), IC1.8 (CE), LED2.2 (A), LED3.2 (A), R5.1, U4.2 (S), U5.1 (IN)

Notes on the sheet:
Note: Charging Current (mA) = 1100(V) / Rprog (kΩ)
On/Off Switch
USB - UART / Programming Circuit
USB Input and Power Path Control
Battery Voltage Sense
Ecternal I2C
Battery Charging
Navigation Switches
Backlight Control
MLX90640 Image Sensor
C91145
3.3V Regulator
Auto Reset Circuit
TFT Display
ESP32 SoC
SD Card

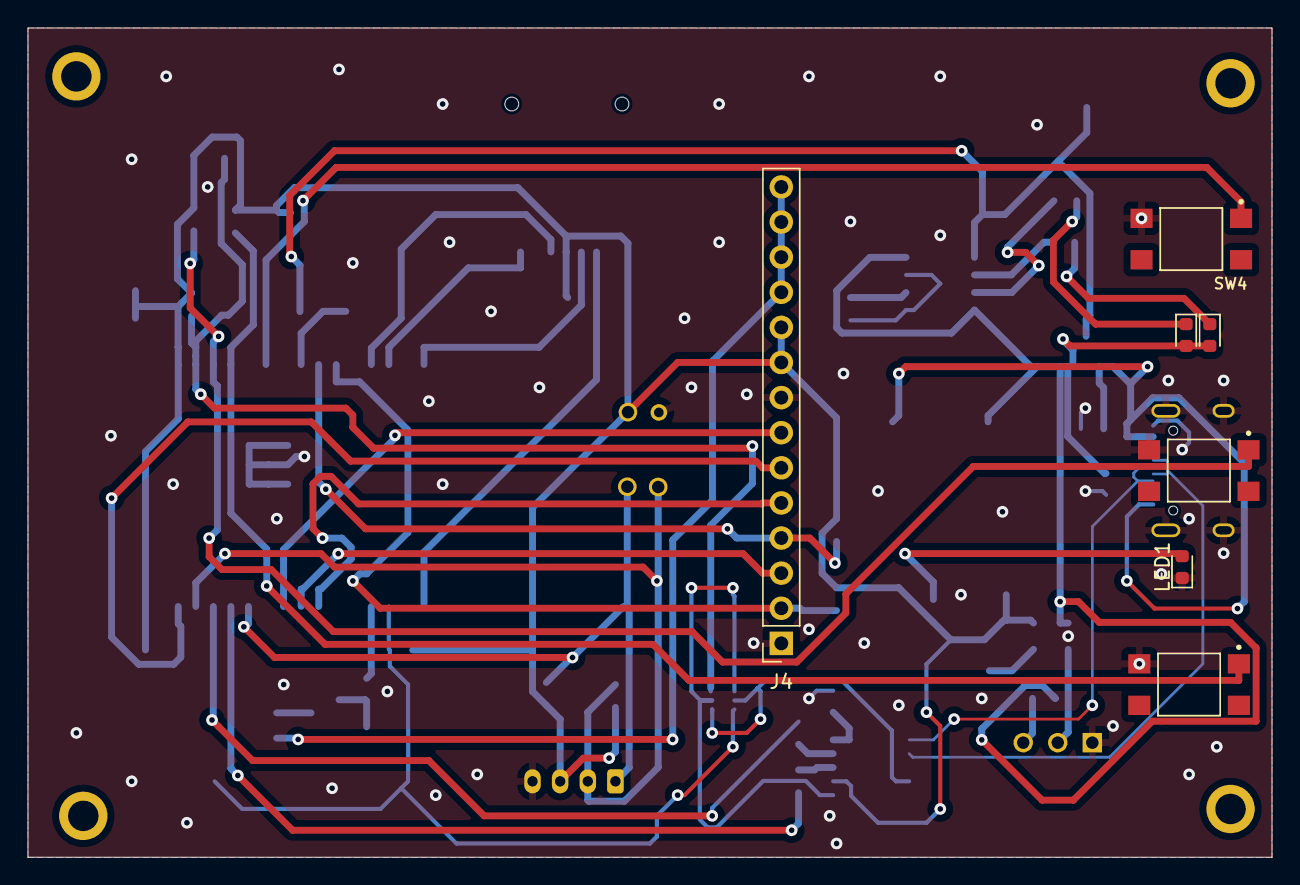
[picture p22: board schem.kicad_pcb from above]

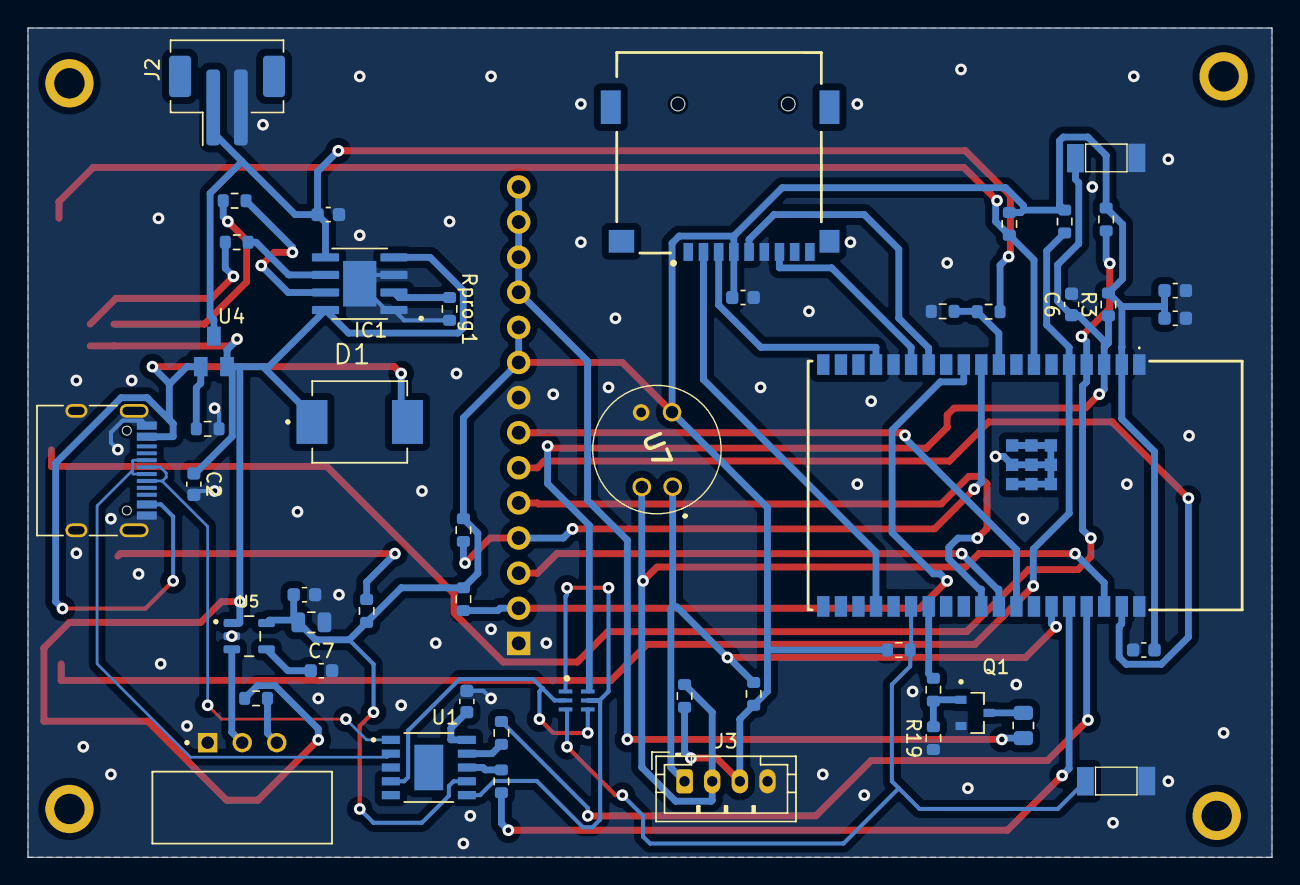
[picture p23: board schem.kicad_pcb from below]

Board: 2 copper layers, 90.0 x 60.0 mm, 60 parts (49 on the bottom side), 45 nets.

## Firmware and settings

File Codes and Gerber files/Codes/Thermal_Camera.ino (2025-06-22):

/*
 * Project Name: MLX90640 Thermal Camera
 * Project Brief: Firmware for Thermal camera built around ESP32 and MLX90640
 * Author: Jobit Joseph
 * Copyright © Jobit Joseph
 * Copyright © Semicon Media Pvt Ltd
 * Copyright © Circuitdigest.com
 * 
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
 */
#include <Preferences.h>
#include <Wire.h>
#include <SPI.h>
#include <SD.h>
#include "FS.h"
#include <Adafruit_MLX90640.h>
#include <TFT_eSPI.h>
#include <AnimatedGIF.h>
#include <Fonts/GFXFF/gfxfont.h>  //Include a library of Fonts
#include "Open_Sans_ExtraBold_10.h"
#include "BootAnimation.h"
#include "success.h"
#include "Error.h"
SPIClass spiSD(HSPI);
#define SD_CS 15
//#define USE_DMA
#define NORMAL_SPEED
#define TFT_WIDTH 240
#define TFT_HEIGHT 320
#define BUFFER_SIZE 240
uint16_t usTemp[BUFFER_SIZE];
#define VBAT_PIN 33
#define BATTV_MAX 4.2  // maximum voltage of battery
#define BATTV_MIN 3.2  // what we regard as an empty battery
#define GIF_IMAGE BootAnimationIMG
#define SGIF_IMAGE success_GIF
#define EGIF_IMAGE Error_GIF
bool dmaBuf = 0;
Adafruit_MLX90640 mlx;
Preferences preferences;
AnimatedGIF gif;
TFT_eSPI tft = TFT_eSPI();
File bmpFile;
float frame[32 * 24];
float batv;
const int upButton = 35;
const int middleButton = 36;
const int downButton = 39;
const int backlightPin = 4;
int interpolationMode = 0;
int AutoScale = 0;
volatile bool MenuChange = false;
volatile bool _upShort = false;
volatile bool _downShort = false;
volatile bool middleShort = false;
volatile bool middlePressed = false;
unsigned long middlePressStartTime = 0;
int Menu = 0, Menuitem = 0;
int BLPWM = 0;
int RefreshRate = 0;
float MinT, MaxT;
String menuItems[7] = { "Auto Scale    : ", "Min Temp      : ", "Max Temp      : ", "Interpolation : ", "Palette       : ", "Refresh Rate  : ", "BackLight     : " };
String ASindex[2] = { "Off", "On" };
String IPindex[6] = { "Nearest Neighbor", "Average", "Bilinear", "Bilinear Fast", "Triangle" };
String RRindex[4] = { "4 Hz", "8 Hz", "16 Hz", "32 Hz" };
float xRatios[240];
float yRatios[320];
float xOppositeRatios[240];
float yOppositeRatios[320];
#define PALETTE_COUNT 10
uint16_t colorPalettes[PALETTE_COUNT][6] = {
  { TFT_BLUE, TFT_CYAN, TFT_GREEN, TFT_YELLOW, TFT_RED, TFT_MAGENTA },
  { TFT_BLACK, TFT_DARKGREY, TFT_LIGHTGREY, TFT_WHITE, TFT_ORANGE, TFT_PINK },
  { TFT_NAVY, TFT_OLIVE, TFT_DARKGREEN, TFT_DARKCYAN, TFT_MAROON, TFT_PURPLE },
  { TFT_BLUE, TFT_GREEN, TFT_DARKGREEN, TFT_ORANGE, TFT_MAROON, TFT_RED },
  { TFT_NAVY, TFT_DARKGREEN, TFT_GREEN, TFT_YELLOW, TFT_ORANGE, TFT_RED },
  { TFT_CYAN, TFT_BLUE, TFT_MAGENTA, TFT_YELLOW, TFT_GREEN, TFT_RED },
  { TFT_WHITE, TFT_ORANGE, TFT_RED, TFT_BLUE, TFT_GREEN, TFT_BLACK },
  { TFT_PURPLE, TFT_MAGENTA, TFT_RED, TFT_ORANGE, TFT_YELLOW, TFT_GREEN },
  { TFT_YELLOW, TFT_PINK, TFT_WHITE, TFT_BLUE, TFT_DARKCYAN, TFT_DARKGREEN },
  { TFT_RED, TFT_YELLOW, TFT_GREEN, TFT_CYAN, TFT_BLUE, TFT_MAGENTA }
};
int paletteIndex = 0;

float tempMin = 20.0;  // Minimum temperature
float tempMax = 32.0;  // Maximum temperature

TFT_eSprite sprite = TFT_eSprite(&tft);


void IRAM_ATTR upButton_ISR() {
  static unsigned long last_interrupt_time = 0;
  unsigned long interrupt_time = millis();

  if (interrupt_time - last_interrupt_time > 200) {  // simple debounce
    _upShort = true;
  }
  last_interrupt_time = interrupt_time;
}

void IRAM_ATTR downButton_ISR() {
  static unsigned long last_interrupt_time = 0;
  unsigned long interrupt_time = millis();

  if (interrupt_time - last_interrupt_time > 200) {  // simple debounce
    _downShort = true;
  }
  last_interrupt_time = interrupt_time;
}

void IRAM_ATTR middleButton_ISR() {
  if (digitalRead(middleButton) == LOW) {
    // Button press event
    if (!middlePressed) {  // If button was not already being pressed
      middlePressed = true;
      middlePressStartTime = millis();  // Save the start time of button press
    }
  } else {
    // Button release event
    if (middlePressed) {                             // If the button was being pressed
      if (millis() - middlePressStartTime < 1000) {  // If the button was pressed for less than 1 second
        middleShort = true;
      }
      middlePressed = false;
      middlePressStartTime = 0;  // Reset the start time of button press
    }
  }
}



void MLXInit() {

  Wire.begin();
  Wire.setClock(1000000);
  if (!mlx.begin()) {
    Serial.println("Failed to initialize MLX90640!");
  }
  mlx.setResolution(MLX90640_ADC_18BIT);
  ConfigRefreshrate();
}
void ConfigRefreshrate() {
  switch (RefreshRate) {
    case 1:
      mlx.setRefreshRate(MLX90640_4_HZ);
      break;
    case 2:
      mlx.setRefreshRate(MLX90640_8_HZ);
      break;
    case 3:
      mlx.setRefreshRate(MLX90640_16_HZ);
      break;
    case 4:
      mlx.setRefreshRate(MLX90640_32_HZ);
      break;
    default:
      break;
  }
}
void ReadConfig() {
  preferences.begin("Config", false);
  String temp;
  temp = preferences.getString("AutoScale", "");
  AutoScale = temp.toInt();
  temp = preferences.getString("MinTe", "");
  MinT = temp.toFloat();
  temp = preferences.getString("MaxTe", "");
  MaxT = temp.toFloat();
  temp = preferences.getString("Imode", "");
  interpolationMode = temp.toInt();
  temp = preferences.getString("PIndex", "");
  paletteIndex = temp.toInt();
  temp = preferences.getString("RefreshRate", "");
  RefreshRate = temp.toInt();
  temp = preferences.getString("BLPWM", "");
  BLPWM = temp.toInt();
  preferences.end();
}
void WriteConfig() {
  preferences.begin("Config", false);
  preferences.putString("AutoScale", String(AutoScale));
  preferences.putString("MinTe", String(MinT));
  preferences.putString("MaxTe", String(MaxT));
  preferences.putString("Imode", String(interpolationMode));
  preferences.putString("PIndex", String(paletteIndex));
  preferences.putString("RefreshRate", String(RefreshRate));
  preferences.putString("BLPWM", String(BLPWM));
  preferences.end();
}

void initSDcard() {
  //spiSD.begin(14, 12, 13, SD_CS);  //CLK,MISO,MOIS,SS
  if (!SD.begin(SD_CS, spiSD)) {
    Serial.println("Card Mount Failed");
    return;
  } else {
    Serial.println("Card Mount Successful");
  }
  uint8_t cardType = SD.cardType();

  if (cardType == CARD_NONE) {
    Serial.println("No SD card attached");
    return;
  }
}
String generateFilename(fs::FS &fs) {
  for (int i = 0; i <= 9999; i++) {
    char filename[23];                               // Allocate the char array
    sprintf(filename, "/ThermalCamera%04d.bmp", i);  // Print formatted string into char array

    if (!fs.exists(filename)) {
      return String(filename);  // Return a String object
    }
  }

  return "";  // return empty string if all filenames are taken
}
int writeBMP(fs::FS &fs, const char *path, TFT_eSprite *sprite) {
  const int width = sprite->width();
  const int height = sprite->height();

  // BMP file header (14 bytes)
  uint8_t bmpFileHeader[14] = { 'B', 'M', 0, 0, 0, 0, 0, 0, 0, 0, 54, 0, 0, 0 };

  // The size of the BMP file in bytes
  uint32_t fileSize = 54 + width * height * 2;
  bmpFileHeader[2] = (uint8_t)(fileSize);
  bmpFileHeader[3] = (uint8_t)(fileSize >> 8);
  bmpFileHeader[4] = (uint8_t)(fileSize >> 16);
  bmpFileHeader[5] = (uint8_t)(fileSize >> 24);

  // BMP info header (40 bytes)
  uint8_t bmpInfoHeader[40] = { 40, 0, 0, 0, 0, 0, 0, 0, 0, 0, 0, 0, 1, 0, 16, 0 };

  bmpInfoHeader[4] = (uint8_t)(width);
  bmpInfoHeader[5] = (uint8_t)(width >> 8);
  bmpInfoHeader[6] = (uint8_t)(width >> 16);
  bmpInfoHeader[7] = (uint8_t)(width >> 24);

  bmpInfoHeader[8] = (uint8_t)(height);
  bmpInfoHeader[9] = (uint8_t)(height >> 8);
  bmpInfoHeader[10] = (uint8_t)(height >> 16);
  bmpInfoHeader[11] = (uint8_t)(height >> 24);

  File file = fs.open(path, FILE_WRITE);
  if (!file) {
    Serial.println("Failed to open file for writing");
    return 0;
  } else {

    //showSavingImageMessage();
    // Write headers
    file.write(bmpFileHeader, 14);
    file.write(bmpInfoHeader, 40);

    // Write pixel data
    for (int y = height - 1; y >= 0; y--) {  // BMP is stored bottom-top
      for (int x = 0; x < width; x++) {
        uint16_t pixel = sprite->readPixel(x, y);
        // Swap red and green channels
        uint16_t r = (pixel >> 11) & 0x1F;
        uint16_t g = (pixel >> 5) & 0x3F;
        uint16_t b = pixel & 0x1F;
        pixel = (b << 11) | (r << 5) | g;
        file.write(pixel >> 8);  // high byte
        file.write(pixel);       // low byte
      }
    }
    file.close();
    return 1;
  }
}


void navigationUpdate() {
  if (_upShort == true) {
    _upShort = false;
    if (Menu == 0) {
      interpolationMode++;
      if (interpolationMode > 4) interpolationMode = 0;
    } else {
      if (Menuitem == 0) {
        AutoScale++;
        if (AutoScale > 1) AutoScale = 1;
      } else if (Menuitem == 1) {
        MinT++;
        if (MinT > 300) MinT = 300;
      } else if (Menuitem == 2) {
        MaxT++;
        if (MaxT > 300) MaxT = 300;
      } else if (Menuitem == 3) {
        interpolationMode++;
        if (interpolationMode > 4) interpolationMode = 4;
      } else if (Menuitem == 4) {
        paletteIndex++;
        if (paletteIndex > 9) paletteIndex = 9;
      } else if (Menuitem == 5) {
        RefreshRate++;
        if (RefreshRate > 3) RefreshRate = 3;
        ConfigRefreshrate();
      } else if (Menuitem == 6) {
        BLPWM = BLPWM + 10;
        if (BLPWM > 100) BLPWM = 100;
        analogWrite(backlightPin, map(BLPWM, 0, 100, 0, 255));  // Turn on backlight
      }
      MenuChange = true;
    }
    WriteConfig();
    Serial.println("Up Short Press");
  }
  if (_downShort == true) {
    _downShort = false;
    if (Menu == 0) {
      paletteIndex = (paletteIndex + 1) % PALETTE_COUNT;
    } else {
      if (Menuitem == 0) {
        AutoScale--;
        if (AutoScale < 0) AutoScale = 0;
      } else if (Menuitem == 1) {
        MinT--;
        if (MinT < 0) MinT = 0;
      } else if (Menuitem == 2) {
        MaxT--;
        if (MaxT < 5) MaxT = 5;
      } else if (Menuitem == 3) {
        interpolationMode--;
        if (interpolationMode < 0) interpolationMode = 0;
      } else if (Menuitem == 4) {
        paletteIndex--;
        if (paletteIndex < 0) paletteIndex = 0;
      } else if (Menuitem == 5) {
        RefreshRate--;
        if (RefreshRate < 0) RefreshRate = 0;
        ConfigRefreshrate();
      } else if (Menuitem == 6) {
        BLPWM = BLPWM - 10;
        if (BLPWM < 10) BLPWM = 10;
        analogWrite(backlightPin, map(BLPWM, 0, 100, 0, 255));  // Turn on backlight
      }
      MenuChange = true;
    }
    WriteConfig();
    Serial.println("down Short Press");
  }
  if (middleShort == true) {
    middleShort = false;
    if (Menu == 0) {
      if (!SD.begin(SD_CS, spiSD)) {
        Serial.println("Card Mount Failed");
        if (gif.open((uint8_t *)EGIF_IMAGE, sizeof(EGIF_IMAGE), GIFDraw1)) {
          Serial.printf("Successfully opened GIF; Canvas size = %d x %d\n", gif.getCanvasWidth(), gif.getCanvasHeight());
          while (gif.playFrame(true, NULL)) {
            sprite.pushSprite(0, 0);  // Push the sprite to screen after every frame
            yield();
          }
          gif.close();
        }
        return;
      } else {
        Serial.println("Card Mount Successful");
      }
      uint8_t cardType = SD.cardType();

      if (cardType == CARD_NONE) {
        Serial.println("No SD card attached");

        if (gif.open((uint8_t *)EGIF_IMAGE, sizeof(EGIF_IMAGE), GIFDraw1)) {
          Serial.printf("Successfully opened GIF; Canvas size = %d x %d\n", gif.getCanvasWidth(), gif.getCanvasHeight());
          while (gif.playFrame(true, NULL)) {
            sprite.pushSprite(0, 0);  // Push the sprite to screen after every frame
            yield();
          }
          gif.close();
        }
        return;
      } else {
        String filename = generateFilename(SD);
        if (filename != "") {
          if (writeBMP(SD, filename.c_str(), &sprite)) {

            if (gif.open((uint8_t *)SGIF_IMAGE, sizeof(SGIF_IMAGE), GIFDraw1)) {
              Serial.printf("Successfully opened GIF; Canvas size = %d x %d\n", gif.getCanvasWidth(), gif.getCanvasHeight());
              while (gif.playFrame(true, NULL)) {
                sprite.pushSprite(0, 0);  // Push the sprite to screen after every frame
                yield();
              }
              gif.close();
            }
          } else {

            if (gif.open((uint8_t *)EGIF_IMAGE, sizeof(EGIF_IMAGE), GIFDraw1)) {
              Serial.printf("Successfully opened GIF; Canvas size = %d x %d\n", gif.getCanvasWidth(), gif.getCanvasHeight());
              while (gif.playFrame(true, NULL)) {
                sprite.pushSprite(0, 0);  // Push the sprite to screen after every frame
                yield();
              }
              gif.close();
            }
          }
        } else {
          Serial.println("Failed to create filename.");

          if (gif.open((uint8_t *)EGIF_IMAGE, sizeof(EGIF_IMAGE), GIFDraw1)) {
            Serial.printf("Successfully opened GIF; Canvas size = %d x %d\n", gif.getCanvasWidth(), gif.getCanvasHeight());
            while (gif.playFrame(true, NULL)) {
              sprite.pushSprite(0, 0);  // Push the sprite to screen after every frame
              yield();
            }
            gif.close();
          }
        }
      }
    } else {
      Menuitem++;
      if (Menuitem > 6) {
        Menuitem = 0;
      }
      MenuChange = true;
    }
    Serial.println("Middle Short Press");
    Serial.print(Menu);
    Serial.print("");
    Serial.println(Menuitem);
  }
  if (middlePressed && !middleShort && millis() - middlePressStartTime > 1000 && middlePressed && !middleShort && millis() - middlePressStartTime < 1500) {
    // If the button is being pressed, no short press has been registered, and it has been over 1 second
    Serial.println("Middle Long Press");
    middlePressed = false;     // Reset the pressed flag
    middlePressStartTime = 0;  // Reset the press start time
    if (Menu == 0) {
      Menu = 1;
      MenuChange = true;
      Menuitem = 0;
    } else {
      Menu = 0;
    }
  }
}

void displayUpdate() {

  if (!mlx.getFrame(frame)) {
    // Failed to get frame, so reinitialize
    MLXInit();
  }

  float tempMinRead = 1000;   // some high value
  float tempMaxRead = -1000;  // some low value
  float tempCenter = 0.0;     // Temperature at center

  // Update the minimum and maximum temperatures read from the sensor
  for (int i = 0; i < 32 * 24; i++) {
    if (frame[i] < tempMinRead) {
      tempMinRead = frame[i];
    }
    if (frame[i] > tempMaxRead) {
      tempMaxRead = frame[i];
    }
    // Get the temperature at center
    if (i == 32 * 12 + 16) {
      tempCenter = frame[i];
    }
  }


  sprite.fillSprite(TFT_BLACK);

if (interpolationMode == 0) {
  // Nearest neighbor interpolation
  for (int y = 0; y < 320; y++) { // Now 320 pixels tall
    int yIndex = (y / 13) * 32; // Scale 24 rows to 320 pixels (320 / 24 ≈ 13.33)
    for (int x = 0; x < 240; x++) { // Now 240 pixels wide
      float val = frame[yIndex + (x / 7)]; // Scale 32 columns to 240 pixels (240 / 32 ≈ 7.5)
      drawPixel(239 - x, y, val); // Adjust for new width
    }
  }
} else if (interpolationMode == 1) {
  for (int y = 0; y < 320; y++) {
    int yIndex = (y / 13) * 32;
    int yNextIndex = ((y / 13) + 1) * 32;
    for (int x = 0; x < 240; x++) {
      int xIndex = x / 7;
      float val = (frame[yIndex + xIndex] + frame[yIndex + xIndex + 1] + frame[yNextIndex + xIndex] + frame[yNextIndex + xIndex + 1]) / 4.0;
      drawPixel(239 - x, y, val);
    }
  }
} else if (interpolationMode == 2) {
  for (int y = 0; y < 320; y++) {
    int yIndex = (y / 13) * 32;
    float y_ratio = (y % 13) / 13.0;
    float y_opposite_ratio = 1 - y_ratio;
    for (int x = 0; x < 240; x++) {
      float x_ratio = (x % 7) / 7.0;
      float x_opposite_ratio = 1 - x_ratio;
      int x_over_7 = x / 7;
      float val = y_opposite_ratio * (x_opposite_ratio * frame[yIndex + x_over_7] + x_ratio * frame[yIndex + x_over_7 + 1]) + y_ratio * (x_opposite_ratio * frame[(yIndex + 32) + x_over_7] + x_ratio * frame[(yIndex + 32) + x_over_7 + 1]);
      drawPixel(239 - x, y, val);
    }
  }
} else if (interpolationMode == 3) {
  int yIndex, xIndex, yNextIndex;
  for (int y = 0; y < 320; y++) {
    yIndex = (y / 13) * 32;
    yNextIndex = yIndex + 32;
    for (int x = 0; x < 240; x++) {
      xIndex = x / 7;
      float val = yOppositeRatios[y] * (xOppositeRatios[x] * frame[yIndex + xIndex] + xRatios[x] * frame[yIndex + xIndex + 1]) + yRatios[y] * (xOppositeRatios[x] * frame[yNextIndex + xIndex] + xRatios[x] * frame[yNextIndex + xIndex + 1]);
      drawPixel(239 - x, y, val);
    }
  }
}

  else if (interpolationMode == 4) {
  for (int y = 0; y < 320; y++) {
    int yIndex = (y / 13) * 32;
    int yNextIndex = ((y / 13) + 1) * 32;
    for (int x = 0; x < 240; x++) {
      int xIndex = x / 7;
      float t = (x % 7) / 7.0f;
      float u = (y % 13) / 13.0f;
      float val;
      if (t > u) {
        val = (1 - t) * frame[yNextIndex + xIndex] + (1 - u) * frame[yIndex + xIndex + 1] + (t + u - 1) * frame[yNextIndex + xIndex + 1];
      } else {
        val = (1 - t) * frame[yIndex + xIndex] + (1 - u) * frame[yNextIndex + xIndex + 1] + (t + u - 1) * frame[yIndex + xIndex + 1];
      }
      drawPixel(239 - x, y, val);
    }
  }
}



  // Display the maximum, minimum and center temperatures as overlay
  sprite.setTextColor(TFT_BLACK);
  sprite.setTextSize(1);

  sprite.setFreeFont(&Open_Sans_ExtraBold_10);

  sprite.drawString("T Min: " + String(tempMinRead) + " C", 15, 290); // Adjusted for 320 height
sprite.drawString("T Max: " + String(tempMaxRead) + " C", 140, 290);
sprite.drawString("Tc: " + String(tempCenter, 1) + "C", 75, 290);
sprite.drawLine(115, 160, 125, 160, TFT_WHITE); // Adjusted crosshair
sprite.drawLine(120, 155, 120, 165, TFT_WHITE);

  detachInterrupt(digitalPinToInterrupt(downButton));
  batv = ((float)analogRead(VBAT_PIN) / 4095) * 2 * 1.07 * 3.3;
  attachInterrupt(digitalPinToInterrupt(downButton), downButton_ISR, CHANGE);
  int batpc = (uint8_t)(((batv - BATTV_MIN) / (BATTV_MAX - BATTV_MIN)) * 100);
  drawBattery(batpc);
  if (Menu == 1) {
  MenuChange = false;
  sprite.fillRect(20, 80, 200, 160, TFT_BLACK); // Adjusted for new dimensions
  sprite.fillRect(20, 80, 200, 10, TFT_WHITE);
  sprite.setTextFont(0);
  sprite.setTextSize(1);
  sprite.setTextColor(TFT_BLACK);
  sprite.drawString("Settings", 100, 81);
  sprite.setTextColor(TFT_WHITE);
  for (int i = 0; i < 7; i++) {
    if (i == Menuitem) sprite.setTextColor(TFT_GREEN);
    int y = 95 + (15 * i);
    sprite.drawString(menuItems[i], 25, y);
    if (i == 0) sprite.drawString(ASindex[AutoScale], 120, y);
    else if (i == 1) sprite.drawString(String(MinT) + " C", 120, y);
    else if (i == 2) sprite.drawString(String(MaxT) + " C", 120, y);
    else if (i == 3) sprite.drawString(IPindex[interpolationMode], 120, y);
    else if (i == 4) sprite.drawString("Palette " + String(paletteIndex), 120, y);
    else if (i == 5) sprite.drawString(RRindex[RefreshRate], 120, y);
    else if (i == 6) sprite.drawString(String(BLPWM) + " %", 120, y);
    sprite.setTextColor(TFT_WHITE);
  }
}
  sprite.pushSprite(0, 0);
}

void drawPixel(int x, int y, float val) {
  int colorIndex;
  if (AutoScale == 1) {
    if (val <= tempMin) {
      colorIndex = 0;
    } else if (val >= tempMax) {
      colorIndex = 5;
    } else {
      // Map the value to a color index between 0 and 5
      colorIndex = int(map(val, tempMin, tempMax, 0, 5));
    }
  } else {
    if (val <= MinT) {
      colorIndex = 0;
    } else if (val >= MaxT) {
      colorIndex = 5;
    } else {
      // Map the value to a color index between 0 and 5
      colorIndex = int(map(val, MinT, MaxT, 0, 5));
    }
  }
  int color = colorPalettes[paletteIndex][colorIndex];
  sprite.drawPixel(x, y, color);
}
void drawBattery(int batpc) {
  int x = 210;
  int y = 10;
  int w = 20;
  int h = 10;
  int color = TFT_RED;  // Default color for the lowest level


  // Determine fill level and color based on batpc
  int fillLevel = 0;
  if (batpc > 75) {
    fillLevel = w;  // 100%
    color = TFT_GREEN;
  } else if (batpc > 50) {
    fillLevel = w * 3 / 4;  // 75%
    color = TFT_GREEN;
  } else if (batpc > 25) {
    fillLevel = w / 2;  // 50%
    color = TFT_BLUE;
  } else if (batpc > 0) {
    fillLevel = w / 4;  // 25%
    color = TFT_BLUE;
  }


  // Draw battery outline
  sprite.drawRect(x, y, w, h, TFT_WHITE);
  sprite.drawRect(x + w, y + h / 4, 2, h / 2, TFT_WHITE);
  // Draw fill level
  if (fillLevel > 0) {
    sprite.fillRect(x + 1, y + 1, fillLevel - 2, h - 2, color);
  }
}
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
void loop() {
  navigationUpdate();
  displayUpdate();
}

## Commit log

2025-04-17 Create sample
2025-06-22 Rename Thermal_Camera Schematics.png to Schematic
2025-06-22 Rename Therml Camera (1).pptx to Thermal Camera.pptx
2025-06-22 Rename WhatsApp Image 2025-06-22 at 16.25.18.jpeg to Schematic.jpeg

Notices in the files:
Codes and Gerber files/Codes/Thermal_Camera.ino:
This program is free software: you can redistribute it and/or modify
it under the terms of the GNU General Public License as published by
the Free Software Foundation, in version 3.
